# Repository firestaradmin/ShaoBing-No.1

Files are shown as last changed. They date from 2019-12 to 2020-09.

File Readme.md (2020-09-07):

# STM32数字网络温度计    ShaoBing-No.1
 ***本项目所有源码文件包括原理图PCB已开源到GitHub上	供大家学习讨论-> [ShaoBing-No.1](https://github.com/firestaradmin/ShaoBing-No.1)***
 ***视频实况已上传至BiliBili  [点我观看](https://www.bilibili.com/video/av80249560)***

---

## 项目概括
- **项目简介：stm32项目，时间片论询结构，驱动OLED显示温度历史曲线，具备物联网功能发送数据至手机APP，可PI计算输出控制温度方案**
- 在这里插入图片描述

- **项目起因：**
&nbsp;&nbsp;&nbsp;&nbsp;大学专业课程设计，需设计一款基于DS18B20 的数字温度计

- **项目要求：**
    1. 实现测温范围 -5~125℃，误差+-0.1℃
	2. 实时采集温度数据，并实时显示记录温度曲线
	3. 设置控制的期望值范围，超出范围则声光报警
- **扩展要求：**
	4. 可与计算机进行通讯 ，可上传温度数据
	5. 具有PI控制算法，可计算输出值
	6. 具有物联网功能，将数据传递至服务器，手机显示温度曲线 基于ESP8266-01S
	7. 位式或连续温度调节
	
- **项目器件：**
	1. STM32F103C8T6 主控芯片*1
	2. DS18B20 测温*1
	3. OLED_IIC 屏幕*1
	4. ESP8266-01S WIFI模块*1
	5. LED灯
	6. 蜂鸣器
	7. etc..

---
## 项目实现

### 1. 原理图设计:
&nbsp;&nbsp;&nbsp;&nbsp;首先进行原理图设计，基于最基础的STM32F103C8T6芯片，将需要用到的元器件模块等等，连接至主控。 		
具体可以参考以下原理图。(如有错误请指正 谢谢)

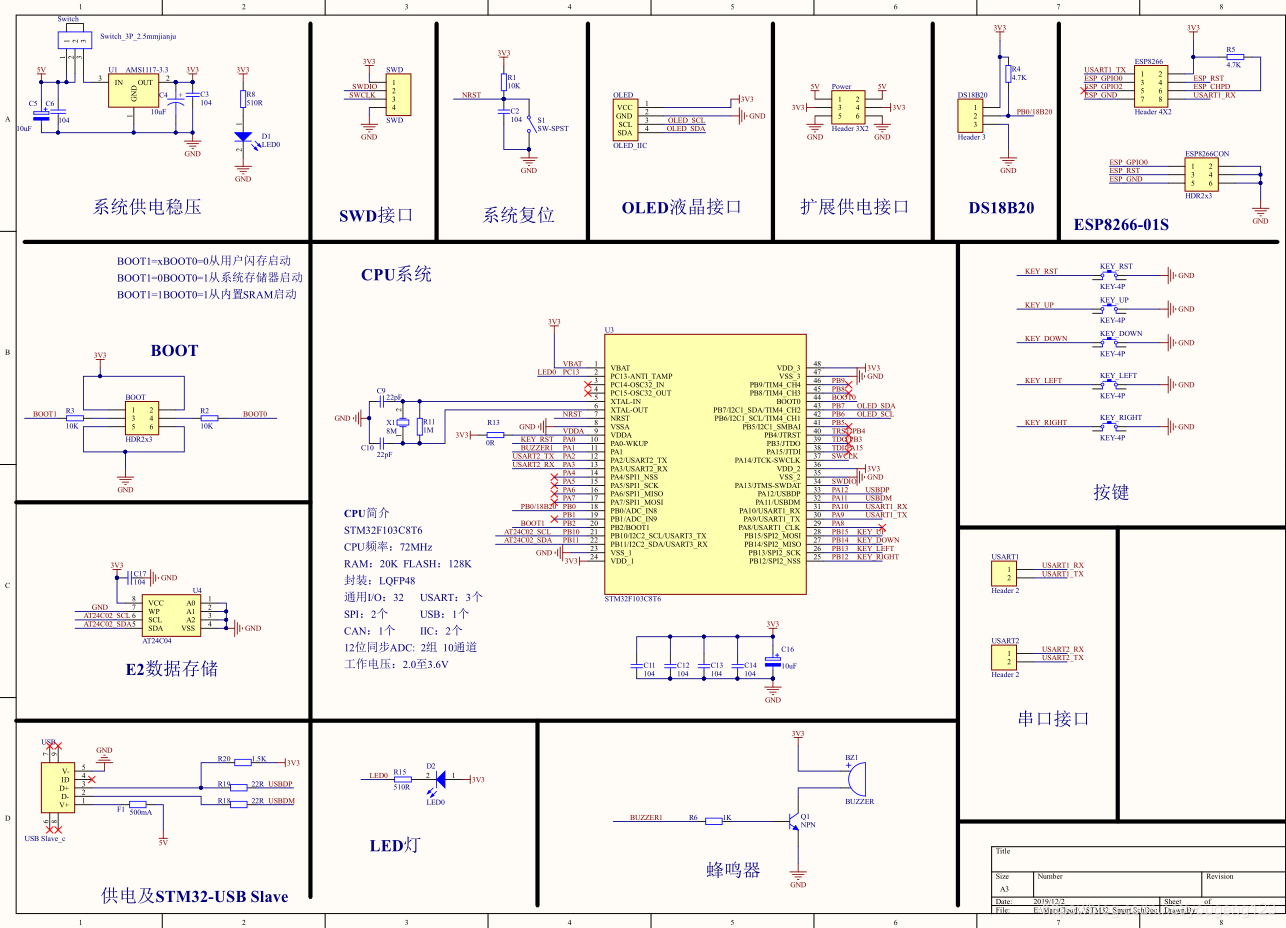
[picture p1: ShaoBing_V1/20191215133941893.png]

### 2. PCB设计：
&nbsp;&nbsp;&nbsp;&nbsp;将原理图画成PCB文件，并找一个商家发板。
&nbsp;&nbsp;&nbsp;&nbsp;每次发板子，等待都是漫长的过程。但是还好，嘉立创每月可以发两次5元的板子，算是对学生和工程师的优惠了
&nbsp;&nbsp;&nbsp;&nbsp;PCB设计如下：(如有错误请指正 谢谢)

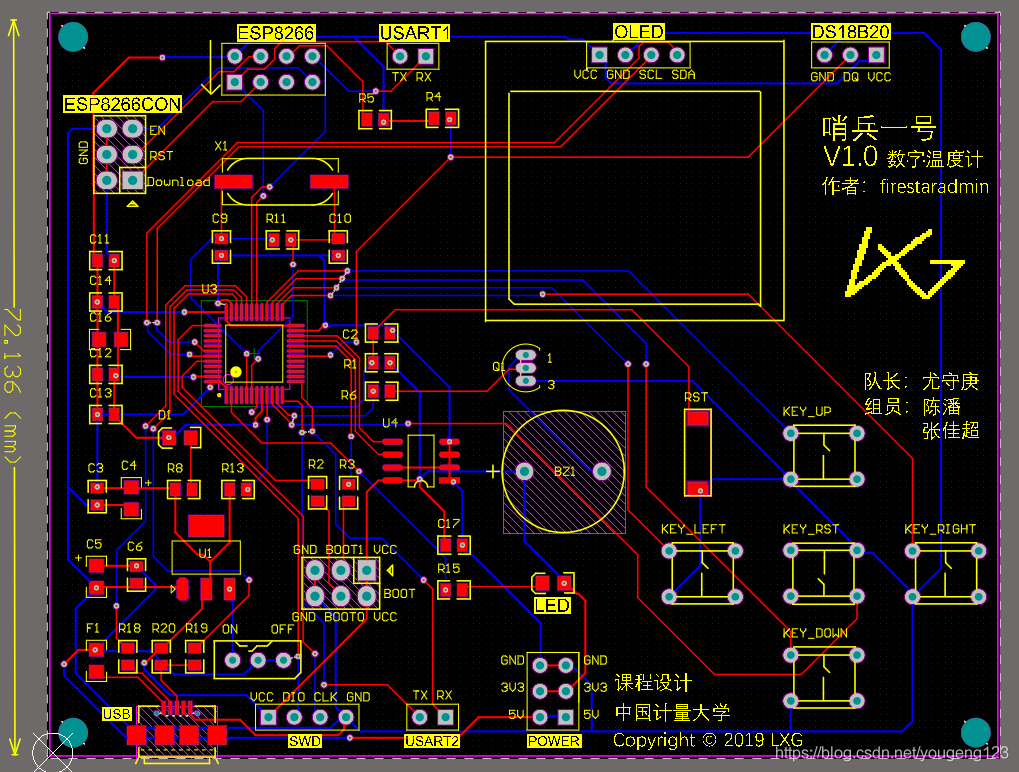
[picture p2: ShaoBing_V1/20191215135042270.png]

### 3. Code 代码部分
&nbsp;&nbsp;&nbsp;&nbsp;板子到手后，就急急忙忙的焊完了，通电测试正常后，开始编写程序。
- 程序部分分为两块：主控STM32的程序和ESP8266-01S的固件
    	主控采用Keil编写，ESP采用Arduino编写，因为Arduino的Wifi库真的很好用。

#### STM32F103主控部分：
&nbsp;&nbsp;&nbsp;&nbsp;主控的思路基本就是，一个循环里做各任务的调用，如按键扫描键值处理，屏幕的动态更新，等等
每个任务都是采用Void形式，不返回数值，全部使用全局变量的标志来实现各函数间的通讯信息传递。
这样的好处就是不会阻塞程序的运行，使得程序的每一个部分都会被执行到。与RTOS等时间片论相比
就有那味儿了！！
&nbsp;&nbsp;&nbsp;&nbsp;主控部分我的大部分精力都花在了OLED的刷新速率优化和按键处理上

&nbsp;&nbsp;&nbsp;&nbsp;OLED最后采用硬件IIC + DMA 的行为传送，在主控RAM里模拟一个1024B的显存，每次显存有变化则刷新至OLED，以OLED-IIC 400Kpbs的速率下，刷新整屏幕只需要 *0.02332s* 理论上刷新率可以达到42帧，而采用DMA传输，还不浪费CPU的资源。

&nbsp;&nbsp;&nbsp;&nbsp;主循环中的进程主要有下面四个

```c
		//while(1)主循环里 顺序执行以下进程，进程基本无阻碍，使用全局变量消息传递机制，可保证实时性。
		myKey_GetKeyValue();//获取键值
		app_Handle_KeyState();//键值处理
		app_Updata_Interface();//界面更新
		app_Dynamic_Display();//动态显示
```
&nbsp;&nbsp;&nbsp;&nbsp;先硬件层上，中断处理按键，是否有按键按下，然后调用

```c
myKey_GetKeyValue();//获取键值
```
根据按下的时间更新按键消息。再根据按键消息来执行各个函数功能。
具体按键处理机制，可以参考我的另一篇博客   *[STM32按键处理机制](https://blog.csdn.net/yougeng123/article/details/103733592)*

&nbsp;&nbsp;&nbsp;&nbsp;之后是界面更新函数进程和动态更新函数进程。
界面更新函数进程主要根据当前页面序号与上次页面序号是否相同，来决定是不是要更新界面，具体定义如下：

```c
//界面显示
typedef enum 
{
	No_Interface = 256,
	Main_Interface = 0,
	Menu_Interface = 1,
	Menu_ENTER_Interface = 2,
	Input_Interface = 3
}Interface_Num_enumTypedef;//页面序号定义

Interface_Num_enumTypedef now_Interface_Num = No_Interface ; 	//当前的页面序号
Interface_Num_enumTypedef next_Interface_Num = Main_Interface;	//下次需要更新到的页面序号
```
页面静态更新函数：
```c
//静态显示 aka 静态页面更新进程
void app_Updata_Interface()
{
	if(now_Interface_Num != next_Interface_Num)
	{
		OLED_RamClear();
		switch (next_Interface_Num)
		{
			case Main_Interface:
				OLED_ShowBMP(0,0,127,63, (u8 *)Interface_Main);
				now_Interface_Num = Main_Interface;
				break;
			case Menu_Interface:
				OLED_ShowBMP(0,0,127,63, (u8 *)Interface_Menu);
				now_Interface_Num = Menu_Interface;
				break;
			case Menu_ENTER_Interface:
				OLED_ShowBMP(0,0,127,63, (u8 *)MENU_ENTER_INTERFACE);
			············省略
```
动态更新每一个主循环进行一次，就会动态更新一次，以便于显示按键动画，温度曲线等动态效果。当处于哪个页面就会更新相应的效果，具体应用具体设计。篇幅过大就不贴出来了。源码已上传至Github

&nbsp;&nbsp;&nbsp;&nbsp;那么界面显示最主要的还是OLED的驱动显示，OLED驱动好了，更新速率上去了，动画才会更加流畅。可以参考   *[ STM32 DMA-IIC刷新OLED屏(理论可达42+帧率)](https://blog.csdn.net/yougeng123/article/details/103734303)*

#### ESP8266-01S部分：
&nbsp;&nbsp;&nbsp;&nbsp;ESP的程序相对来说简单了很多，需要做的只是连接WIFI然后串口接受温度数据，并HTTP-POST请求上传数据置服务器即可。（其实可以做的复杂点，就是自己设计一个通讯协议，这样通讯更严谨，但由于时间问题，就草草的设计了简单的通讯，无帧头帧尾和校验位）

&nbsp;&nbsp;&nbsp;&nbsp;//本来打算加个选择连接WIFI的功能，并且增加软键盘输入密码等功能，但是学期末了，时间不太够了，想想觉得很麻烦，就算了，直接将WIFI名和密码写在了程序里。

&nbsp;&nbsp;&nbsp;&nbsp;ESP的程序编写用到了Arduino的ESP8266的库，网上可以下载到，也可以到我的GitHub上下载。

&nbsp;&nbsp;&nbsp;&nbsp;思路：先连接WIFI  然后一直循环在串口接收的函数里，判断是否有正确的温度数据被接受，有则POST请求至服务器

```cpp
char* getValue()
{
  while (true)
  {
    if (Serial.available() > 0)
    {
      inByte = Serial.read();
      //Serial.print(inByte);
      if (inByte == '[')
      {
        isCommand = true;
        rxBuffer_tail = 0;
        //rxBuffer[0] = 0;
      }
      else if (inByte == ']')
      {
        isCommand = false;
        rxBuffer[rxBuffer_tail] = '\0';
        return rxBuffer;
      }
      else if (isCommand)
      {
        rxBuffer[rxBuffer_tail++] = inByte;
      }
    }
  }
}
```
&nbsp;&nbsp;&nbsp;&nbsp;具体代码已开源至GitHub。

@firestaradmin

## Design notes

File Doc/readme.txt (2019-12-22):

// DS18B20 数字温度计
功能需求：

1.实现测温范围 -5~125℃，误差+-0.1℃
2.实时温度数据，和温度曲线
3.设置控制的期望值范围，超出范围则声光报警
扩展：
4.计算机串口通讯 传递 温度值
//5.PI设置，并计算输出  显示就好
6.物联网功能，将数据传递至手机 采用ESP8266Wifi
//（7.位式或连续温度调节）

Needs:
1.  STM32F103C8T6 主控芯片*1
2.	DS18B20测温*1
3.	OLED_IIC 屏幕*1
4.	ESP8266-01S WIFI模块*1
5.	LED
6.	蜂鸣器

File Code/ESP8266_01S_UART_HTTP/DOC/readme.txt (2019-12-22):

"[LinkStart]" :开始连接WIFI    连接成功则返回 "[Connected]"
"[BreakLink]" :断开WIFI		断开则返回 "[UnConnected]"
"[18.8]" :	温度数据

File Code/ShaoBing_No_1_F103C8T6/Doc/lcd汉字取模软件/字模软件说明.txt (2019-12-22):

几点说明：
1。打开功能是专门用于对C语言文件自动提取显示所需要的汉字，进行点阵码数据转换的，
   在您的C语言程序中，有一点需要特别留意：您的注解中请不要使用双引号，否则会引起
   提取错误。
   软件包中的文件ee.c作为一个简单例程供提取测试用。

2。提取以后的点阵码可以随意修改点阵数据，使用鼠标的左键为加一点，右键为擦除一点。
   修改完毕请按旁边的确认键将数据记录到点阵码中，否则您的修改将自动放弃。

3。点阵码可以随意平移，请谨慎使用。平移之前请查看一遍所有的字符点阵图，平移有可能
   会丢失边界点，移出了边界的点阵将被丢弃，不可恢复。
   平移前请确认是否有必要进行全体字符一起移动。

4。用户自定义特殊字符的建立，首先选定点阵数据，在下面的汉字输入窗口输入几个您不使
   用的汉字，确认。然后生成了这些汉字的点阵码，再将他们清空（使用平移按钮中间的那
   块抹布），就可以用鼠标描绘你的图案了，最后别忘了打“确认”键。

5。ASCII字符可以自动提取0x20~0x7f的全部，最后一个0x7f一般都没有用，可以手工将它删
   除，也可以利用它做一个简单的特殊字符。
   汉字库中也包含有ascii字符，但是经查对与这三个ascii库基本一样，所以就不再重复。

6。保存文件：C语言格式的默认为.h类型，汇编格式的默认为.inc类型，只要将他们加入到
   您的工程中就可以了。

7。新增加了自动添加下划线功能。这项功能在做点阵显示和修改的时候并不出现下划线，
   设置了以后仅仅在最后的输出文件中出现，以免干扰编辑修改。

8。扩充对windows汉字的直接提取，从16~96范围内可以任意设定选取。主要用于制作界面的
   开机封面少量标识性汉字。

9。扩充了对ascii小字库5x8以及大字库20*40/24*48的支持，毕竟字库文件比较工整。

-----------------2004.12.10更新内容

10。增加了字模输出格式的选择，可以将汉字码与点阵数据分开列表；

11。增加了对单色.bmp文件的支持，可以从原有的bitmap文件上截取一部分作为点阵码数据
   输出，点阵图案可以随意修改。

12。bitmap用户自建方案，可以先设定好图形的宽度和高度，然后用打开图形文件窗口下选
   择取消，自动生成一块空白的图板。

13。图形区域显示的图形点阵可以用调节拉条进行放大或缩小。

14。图形编辑的鼠标可以单点加点也可以慢速拖线，擦除也可以，只是左右健的区别。

-----------------2004.12.11更新内容

15。字模部分当采用非结构型格式输出的时候添加了对应汉字标识，便于对照查看。

16。bitmap文件的读入前可以设定是否反白读取。

17。增加了图形编辑板直接保存便于为制作说明书等提供贴图。

-----------------2004.12.20更新内容
18。修正了华文中宋汉字模生成过程中的切(底)边现象

配合lcmsim排版仿真软件一起使用，可以大大提高单片机编程的工作效率。

晓奇  2004.12更新

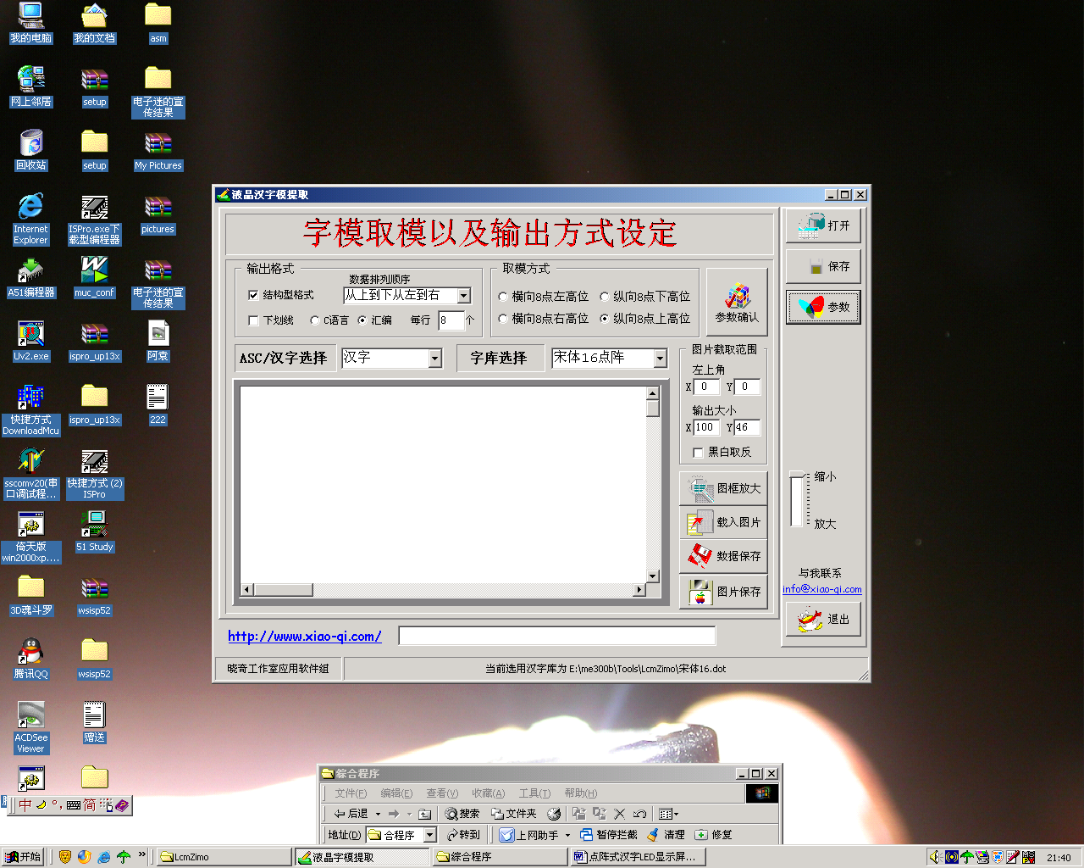
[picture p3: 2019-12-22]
Code/ShaoBing_No_1_F103C8T6/Doc/lcd汉字取模软件/实际应用.bmp

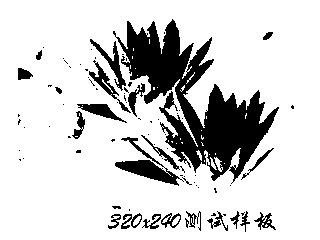
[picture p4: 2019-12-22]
Code/ShaoBing_No_1_F103C8T6/Doc/lcd汉字取模软件/Water.bmp

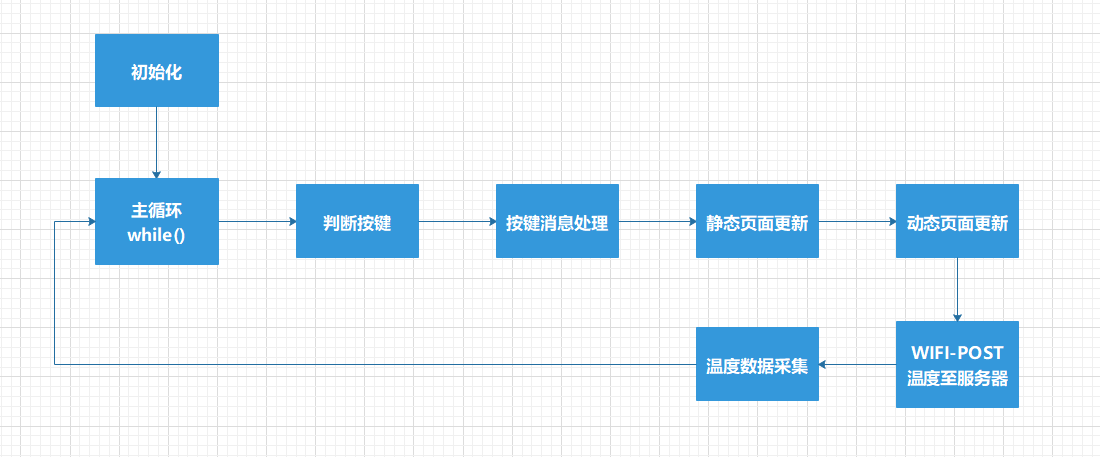
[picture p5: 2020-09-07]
程序流程图.png

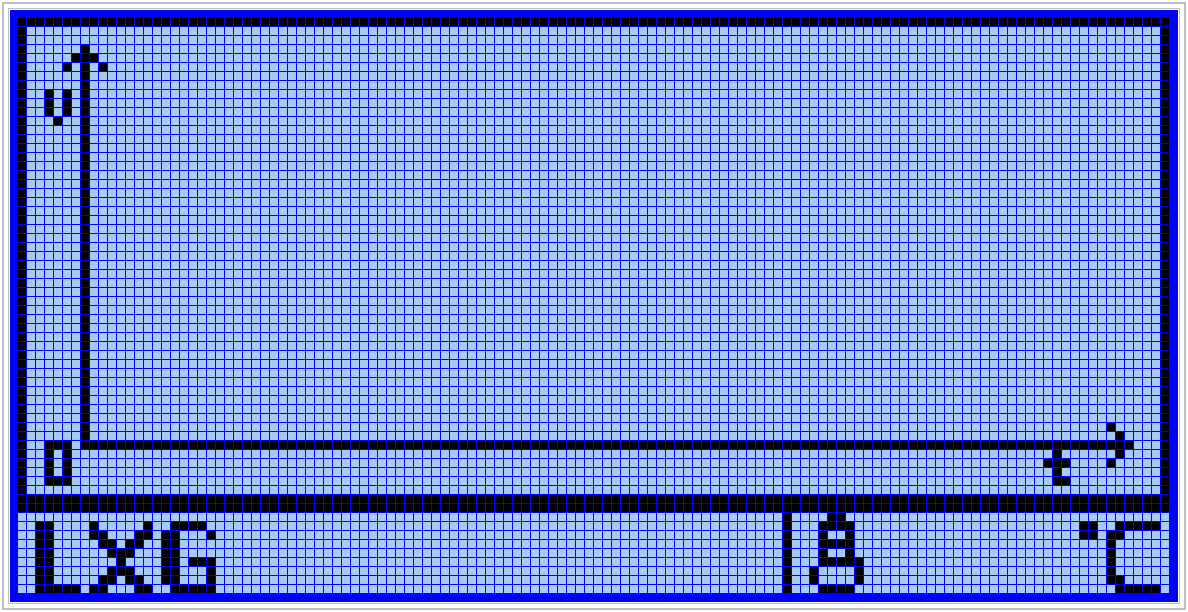
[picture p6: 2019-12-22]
Code/ShaoBing_No_1_F103C8T6/Doc/主界面.bmp

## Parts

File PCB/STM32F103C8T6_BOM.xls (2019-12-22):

Comment | Description | Designator | Footprint | LibRef | Quantity
HDR2x3 | Connector | BOOT, ESP8266CON | PIN-2x3-2.54-1.0 | HDR2x3 | 2
BUZZER | Buzzer | BZ1 | BUZZER_12*9.5_pin_7.6mm | BUZZER | 1 |  | 2
104 | Capacitor | C2, C3, C6, C11, C12, C13, C14, C17 | RC0603 | CAP1, Cap | 8
10uF | Capacitor, [NoValue] | C4, C5, C16 | RC0805 | CAPACITOR POL, ELECTRO2 | 3
22pF | Capacitor | C9, C10 | RC0603 | CAP1 | 2
LED0 | Typical INFRARED GaAs LED | D1, D2 | LED0805 | LED0 | 2
Header 3 | Header, 3-Pin | DS18B20 | HDR1X3 | Header 3 | 1
Header 4X2 | Header, 4-Pin, Dual row | ESP8266 | HDR2X4 | Header 4X2 | 1
500mA | Resistor | F1 | RC0805 | Res2 | 1 |  | 0.5
KEY-4P | Key | KEY_DOWN, KEY_LEFT, KEY_RIGHT, KEY_RST, KEY_UP | KEY_6.5x4.5 | KEY-4P | 5
OLED_IIC |  | OLED | OLED_IIC | OLED_IIC | 1 |  | 12
Header 3X2 | Header, 3-Pin, Dual row | Power | IDE3X2-2.54 | Header 3X2 | 1
NPN | NPN Bipolar Transistor | Q1 | TO-92 | NPN | 1
10K |  | R1, R2, R3 | RC0603 | R | 3
4.7K |  | R4, R5 | RC0603 | R | 2
1K | Resistor | R6 | RC0603 | Res2 | 1
510R |  | R8, R15 | RC0603 | R | 2
1M |  | R11 | RC0603 | R | 1
0R |  | R13 | RC0603 | R | 1
22R | Resistor | R18, R19 | RC0603 | Res2 | 2
1.5K | Resistor | R20 | RC0603 | Res2 | 1
SW-SPST | Single-Pole, Single-Throw Switch | S1 | SMT-KEY | SW-SPST | 1
SWD | Header, 4-Pin | SWD | HDR1X4 | Header 4 | 1
Switch_3P_2.5mmjianju |  | Switch | Switch_3p_2.5mmjianju | Switch_3P_2.5mmjianju | 1
AMS1117-3.3 |  | U1 | SOT223 | LT1085CM-3.3 | 1 |  | 0.2
STM32F103C8T6 |  | U3 | LQFP48 | STM32F103C8T6 | 1 |  | 7
AT24C04 |  | U4 | SOIC-8P | EPROM | 1 |  | 0.5
Header 2 | Header, 2-Pin | USART1, USART2 | HDR1X2 | Header 2 | 2
USB Slave_c | USB Connector | USB | MICRO USB CONNECTOR TYPEB-ST-MC-5F-01 | MICRO USB CONNECTOR TYPEB | 1
8M | Crystal Oscillator | X1 | SMD49S | XTAL_SMD | 1 |  | 0.2
DS18B20 |  |  |  |  |  |  | 5
Usb wire |  |  |  |  |  |  | 1.5
ESP8266-01s |  |  |  |  |  |  | 7
cap and res |  |  |  |  |  |  | 2
PCB |  |  |  |  |  |  | 5
 |  |  |  |  |  | 合计 | 42.9

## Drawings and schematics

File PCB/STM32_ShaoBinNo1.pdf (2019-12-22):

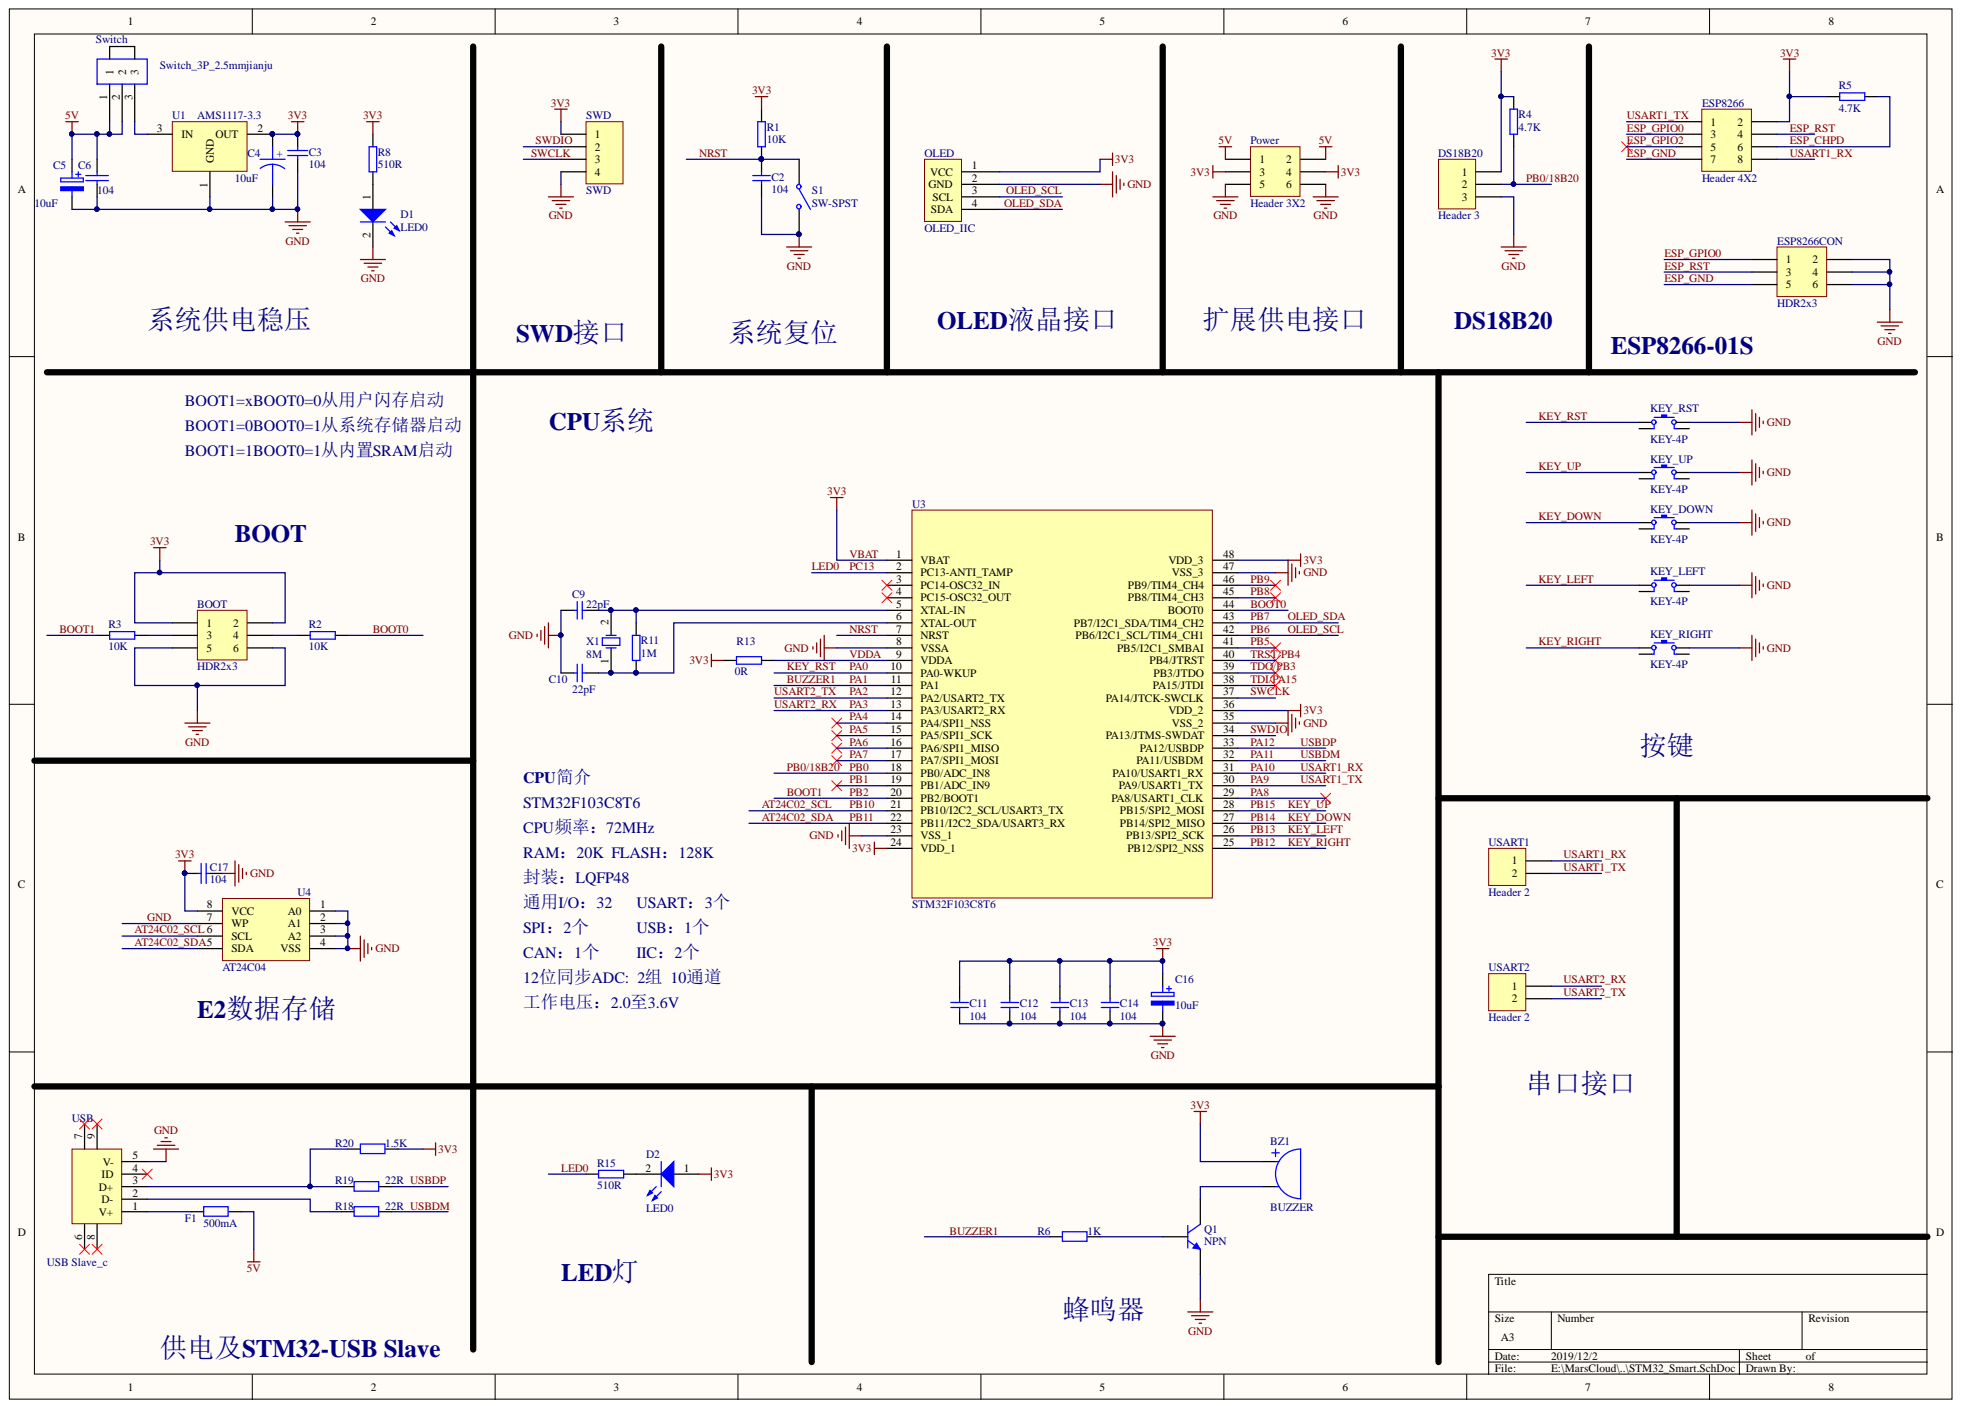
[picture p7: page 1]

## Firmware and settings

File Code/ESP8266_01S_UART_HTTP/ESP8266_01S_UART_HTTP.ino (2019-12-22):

#include <ESP8266WiFi.h>
#include <ESP8266HTTPClient.h>

char* MYSSID = "CMCC-AUTO-G";
char* MYPASSWORD = "12344321";

const char * MYHOST = "https://cjlu.online/ShaoBing/Fuck.php";
const int  MYHOSTPORT = 80;
//const char *keys[] = {"res","info"};//需要收集的响应头的信息
boolean isCommand = false;
boolean isConnectedFlag = false;
boolean dataWaitPOST = false;
boolean receiveOver = false;
char inByte;
String RxDataString;

boolean isWIFIConnected() {
  isConnectedFlag = !(WiFi.status() == WL_CONNECT_FAILED || WiFi.status() == WL_CONNECTION_LOST || WiFi.status() == WL_DISCONNECTED);
  Serial.print(isConnectedFlag);
  return isConnectedFlag;
}

boolean getIsWIFIConnected()
{
    isConnectedFlag =  WiFi.isConnected();
    return isConnectedFlag;
}
  
void wifiConnect(char* ssid, char* passwd) {
  WiFi.begin(ssid, passwd);
  Serial.printf("Connecting to %s\n", ssid);
  while (WiFi.status() != WL_CONNECTED) {
    delay(500);
    Serial.print(".");
  }
  Serial.println();
  Serial.printf("Connected to %s\n", ssid);
  Serial.println("[Connected]");
  isConnectedFlag = true;
}


String  getValue()
{
  String temp;
  while (true)
  {
        if (Serial.available() > 0)
        {
              inByte = Serial.read();
            
              if (inByte == '[')
              {
                isCommand = true;
                temp = "";
              }
              else if (inByte == ']')
              {
                isCommand = false;
                temp += '\0';
                //dataWaitPOST = true;
                receiveOver = true;
                //return temp;
              }
              else if (isCommand)
              {
                temp += inByte;
              }

              if(receiveOver)
              {
                receiveOver = false;
                  if(temp == "LinkStart")
                  {
                      if(getIsWIFIConnected())
                      {
                          Serial.println("[Connected]");
                        }
                        else
                        {
                          wifiConnect(MYSSID,MYPASSWORD);
                          }
                    
                    }
                  else if(temp == "BreakLink")
                  {
                      WiFi.disconnect(false);
                      Serial.println("[UnConnected]");
                    }
                    else
                    {
                       dataWaitPOST = true;
                        return temp;
                      }
                           
                   
              }
          
        }
  }
}

void setup() {
  Serial.begin(115200);

  WiFi.mode(WIFI_STA);
  
  

}

void loop() {
   RxDataString = getValue();
   if(WiFi.isConnected() && dataWaitPOST == true)
   {
        HTTPClient http;
        WiFiClient client;
        Serial.print("HTTP begin...\n");
        bool httpResponse_BOOL = http.begin("http://47.103.115.138/ShaoBing/Fuck.php");
        if (httpResponse_BOOL) {  // HTTP
        
        http.setReuse(0);
        http.setTimeout(1000);
        http.setUserAgent("Your G");
        http.setAuthorization("esp8266","boge");//用户校验信息
        http.addHeader("G","firestaradmin");
        
        int responseCode = http.POST(RxDataString);
        delay(200);
        Serial.println(responseCode);
        Serial.println(http.getString());
        dataWaitPOST = 0;
      }
      else if(!httpResponse_BOOL)
      {
          Serial.println("[HttpFailed]");
      }
      
      //delay(2000);
  }
  else
  {
    isConnectedFlag = false;
    Serial.println("[UnConnected]");
    //wifiConnect(MYSSID,MYPASSWORD);     
  }
}

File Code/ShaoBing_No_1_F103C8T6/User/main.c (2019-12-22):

/************************************************************************************
*  Copyright (c), 2019, LXG.
*
* FileName		:main.c
* Author		:firestaradmin
* Version		:1.0
* Date			:2019.12.8
* Description	:程序入口
* History		:
*
*
*************************************************************************************/
#include <stm32f10x.h>  
#include "stm32f10x_it.h"
#include "OLED_I2C_Buffer.h"
#include "delay.h"
#include "DS18B20.h"
#include "myUSART.h"
#include "myShaoBingApp.h"
#include "myKey.h"
#include "AT24C04.h"


unsigned short TIM4_Timer5MsCounter = 0;	//5MS计数器
unsigned char TIM4_Timer1SCounter = 0;		//1S计数器
unsigned char OLED_CurveNeedDrawFlag = 0;	//OLED曲线需要绘制标志
unsigned char DS18B20_NeedUpdataFlag = 0;	//DS18B20数据需要更新标志
unsigned char alarmNeedProcessFlag = 0;		//警报进程需处理标志
unsigned char alarmStatusFlag = 0;			//警报状态标志
unsigned char alarmExceededFlag = 0;		//超出警报上下限标志
unsigned char samplingPeriod5ms = 100;		//采样周期
unsigned char voiceLightAlarmFlag = 0;		//警报使能标志
unsigned char wifiFlag = 0;					//WIFI使能标志


void TIM4_Int_Init(u16 arr,u16 psc);//TIM4初始化
void SYS_Configuration(void);//初始化
void alarm_Init(void);//警报初始化
void alarmStop(void);//停止声光报警
void alarmGOGOGO(void);//开启声光报警
void readValue(void);//读取AT24C04的值

int main()
{
	SYS_Configuration(); //初始化
	OLED_STARTUP_VIDEO();//开机动画
	DS18B20_UpdataTempx5Average();	//检测一次DS18B20温度数据
	readValue();//读取AT24C04的值
	while(1)
	{	
		//while(1)主循环里 顺序执行以下进程，进程基本无阻碍，使用全局变量消息传递机制，可保证实时性。
		myKey_GetKeyValue();//获取键值
		app_Handle_KeyState();//键值处理
		app_Updata_Interface();//界面更新
		app_Dynamic_Display();//动态显示
		
		//
		if(DS18B20_NeedUpdataFlag)//DS18B20读取温度数据
		{
			if(DS18B20_State == DS18B20_CONNECT_SUCCESS)
				DS18B20_UpdataTempx5Average();	
		}
		
		if(DS18B20_Temperature > alarmTEMPHIGH || DS18B20_Temperature < alarmTEMPLOW)//判断报警温度上下限是否超出
		{
			alarmExceededFlag = 1;
		}
		else
		{
			alarmExceededFlag = 0;
		}
			
		if(httpNeedPostFlag && wifiIsConnected && wifiFlag)//判断是否需要WIFI-POST
		{
			myUSART_SentTempData();
			httpNeedPostFlag = 0;
		}
		
		if(voiceLightAlarmFlag && alarmNeedProcessFlag && alarmExceededFlag)//判断是否要打开警报
		{
			alarmNeedProcessFlag = 0;
			if(alarmStatusFlag == 0)
			{
				alarmGOGOGO();
			}
			else
			{
				alarmStop();
			}
		}
		else if(!(voiceLightAlarmFlag && alarmExceededFlag))
		{
			alarmStop();
		}

	}
	
}




//系统初始化
void SYS_Configuration(void)
{
	//--**********--内的代码不可删除 ，否则上电后需要手动复位一次
	//				此版硬件电路问题(适当延时，等待晶振可正常工作)
	//--********************************-----
	u32 i,j;
	for(i = 0; i <= 65535; i++ )
	{
		for(j = 0; j <= 50; j++ );
	}
	SystemInit();
	//--********************************-----
	
	
	NVIC_PriorityGroupConfig(NVIC_PriorityGroup_2);	//设置NVIC中断分组2  抢占2位:响应2位 
	AT24C02_I2C_Configuration();
	DelayInit();
	OLED_Init();
	ds18b20_init();
	UART1_init();
	myKey_Init();
	
	//DelayS(2);
	TIM4_Int_Init(1000,360);//5ms OneTime
	alarm_Init();
 
}



void TIM4_IRQHandler(void)   //TIM4中断
{
	if (TIM_GetITStatus(TIM4, TIM_IT_Update) != RESET)  //检查TIM3更新中断发生与否
	{
		TIM_ClearITPendingBit(TIM4, TIM_IT_Update  );  //清除TIMx更新中断标志 
			
		//TIM_Cmd(TIM4, DISABLE); 
		TIM4_Timer5MsCounter++;
		if(TIM4_Timer5MsCounter % samplingPeriod5ms == 0)
		{
			
			OLED_CurveNeedDrawFlag = 1;
			DS18B20_NeedUpdataFlag = 1;
			
			//httpNeedPostFlag = 1;
			
		}
		if(TIM4_Timer5MsCounter % 10 == 0)
		{
			alarmNeedProcessFlag = 1;
		}
		if(TIM4_Timer5MsCounter % 200 == 0)
		{
			httpNeedPostFlag = 1;
		}
		if(TIM4_Timer5MsCounter >= 65500)
		{
			TIM4_Timer5MsCounter = 0;
		}
	}
}


//这里时钟选择为APB1的2倍，而APB1为36M
//arr：自动重装值。
//psc：时钟预分频数
//一次中断的时间为t：t = (arr * psc / APB1*2) * 1000 ms
void TIM4_Int_Init(u16 arr,u16 psc)
{
    TIM_TimeBaseInitTypeDef  TIM_TimeBaseStructure;
	NVIC_InitTypeDef NVIC_InitStructure;
	
	RCC_APB1PeriphClockCmd(RCC_APB1Periph_TIM4, ENABLE); //时钟使能
	
	TIM_DeInit(TIM4);
	//定时器TIM4初始化
	TIM_TimeBaseStructure.TIM_Period = arr; //设置在下一个更新事件装入活动的自动重装载寄存器周期的值	
	TIM_TimeBaseStructure.TIM_Prescaler = psc; //设置用来作为TIMx时钟频率除数的预分频值
	TIM_TimeBaseStructure.TIM_ClockDivision = TIM_CKD_DIV1; //设置时钟分割:TDTS = Tck_tim
	TIM_TimeBaseStructure.TIM_CounterMode = TIM_CounterMode_Up;  //TIM向上计数模式
	TIM_TimeBaseInit(TIM4, &TIM_TimeBaseStructure); //根据指定的参数初始化TIMx的时间基数单位
 
	TIM_ITConfig(TIM4,TIM_IT_Update,ENABLE ); //使能指定的TIM4中断,允许更新中断
 
	//中断优先级NVIC设置
	NVIC_InitStructure.NVIC_IRQChannel = TIM4_IRQn;  //TIM4中断
	NVIC_InitStructure.NVIC_IRQChannelPreemptionPriority = 2;  //先占优先级0级
	NVIC_InitStructure.NVIC_IRQChannelSubPriority = 2;  //从优先级0级
	NVIC_InitStructure.NVIC_IRQChannelCmd = ENABLE; //IRQ通道被使能
	NVIC_Init(&NVIC_InitStructure);  //初始化NVIC寄存器
 
 
	TIM_Cmd(TIM4, ENABLE);  //使能TIM4					 
}


void alarm_Init(void)
{
	//PA1 LED
	//PC13 Alarm
	RCC_APB2PeriphClockCmd(RCC_APB2Periph_GPIOC | RCC_APB2Periph_GPIOA, ENABLE);
	GPIO_InitTypeDef GPIO_InitStructure;
	
	GPIO_InitStructure.GPIO_Pin =  GPIO_Pin_1;
	GPIO_InitStructure.GPIO_Speed = GPIO_Speed_50MHz;
	GPIO_InitStructure.GPIO_Mode = GPIO_Mode_Out_PP;//上拉输入
	GPIO_Init(GPIOA, &GPIO_InitStructure);
	
	GPIO_InitStructure.GPIO_Pin =  GPIO_Pin_13;
	GPIO_Init(GPIOC, &GPIO_InitStructure);
	
	
}


void alarmStop(void)
{
	GPIO_SetBits(GPIOC,GPIO_Pin_13);
	GPIO_ResetBits(GPIOA,GPIO_Pin_1);
	alarmStatusFlag = 0;
}

void alarmGOGOGO(void)
{
	GPIO_ResetBits(GPIOC,GPIO_Pin_13);
	GPIO_SetBits(GPIOA,GPIO_Pin_1);
	alarmStatusFlag = 1; 
}



  


void readValue()
{

	TEMPHIGH = *((float*)AT24C04_Read_Page(AT24C04_PAGE0, TEMPHIGH_ADDR, 4));
	TEMPLOW = *((float*)AT24C04_Read_Page(AT24C04_PAGE0, TEMPLOW_ADDR, 4));
	samplingPeriod5ms = *((u8*)AT24C04_Read_Page(AT24C04_PAGE0, samplingPeriod5ms_ADDR, 1));
	alarmTEMPHIGH = *((float*)AT24C04_Read_Page(AT24C04_PAGE0, alarmTEMPHIGH_ADDR, 4));
	alarmTEMPLOW = *((float*)AT24C04_Read_Page(AT24C04_PAGE0, alarmTEMPLOW_ADDR, 4));
	
	wifiFlag = AT24C04_Read_Byte(AT24C04_PAGE0, wifiFlag_ADDR);
	voiceLightAlarmFlag = AT24C04_Read_Byte(AT24C04_PAGE0, voiceLightAlarmFlag_ADDR);
	
}
